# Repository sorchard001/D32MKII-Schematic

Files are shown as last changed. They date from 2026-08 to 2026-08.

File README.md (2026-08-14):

# Dragon 32 MKII Schematic

Captured in KiCad by Stewart Orchard 2015-2026

Original design by Dragon Data Ltd circa 1982

## Why?

The published Dragon schematics do not appear to include MKII versions, which can be a problem for repairs as there are differences in the memory configuration, the video circuit and logic gate pin numbers. I captured this information around the year 1998 with reference to the existing ISS2 schematics, a multimeter and a real MKII ISS6 main board, and have finally got round to recording it as a KiCad project.

## Disclaimer

Much as I would like to think that I've got this 100% correct, there is always the chance that there are mistakes and omissions. I would recommend checking that the information is accurate before using this schematic for anything potentially expensive.

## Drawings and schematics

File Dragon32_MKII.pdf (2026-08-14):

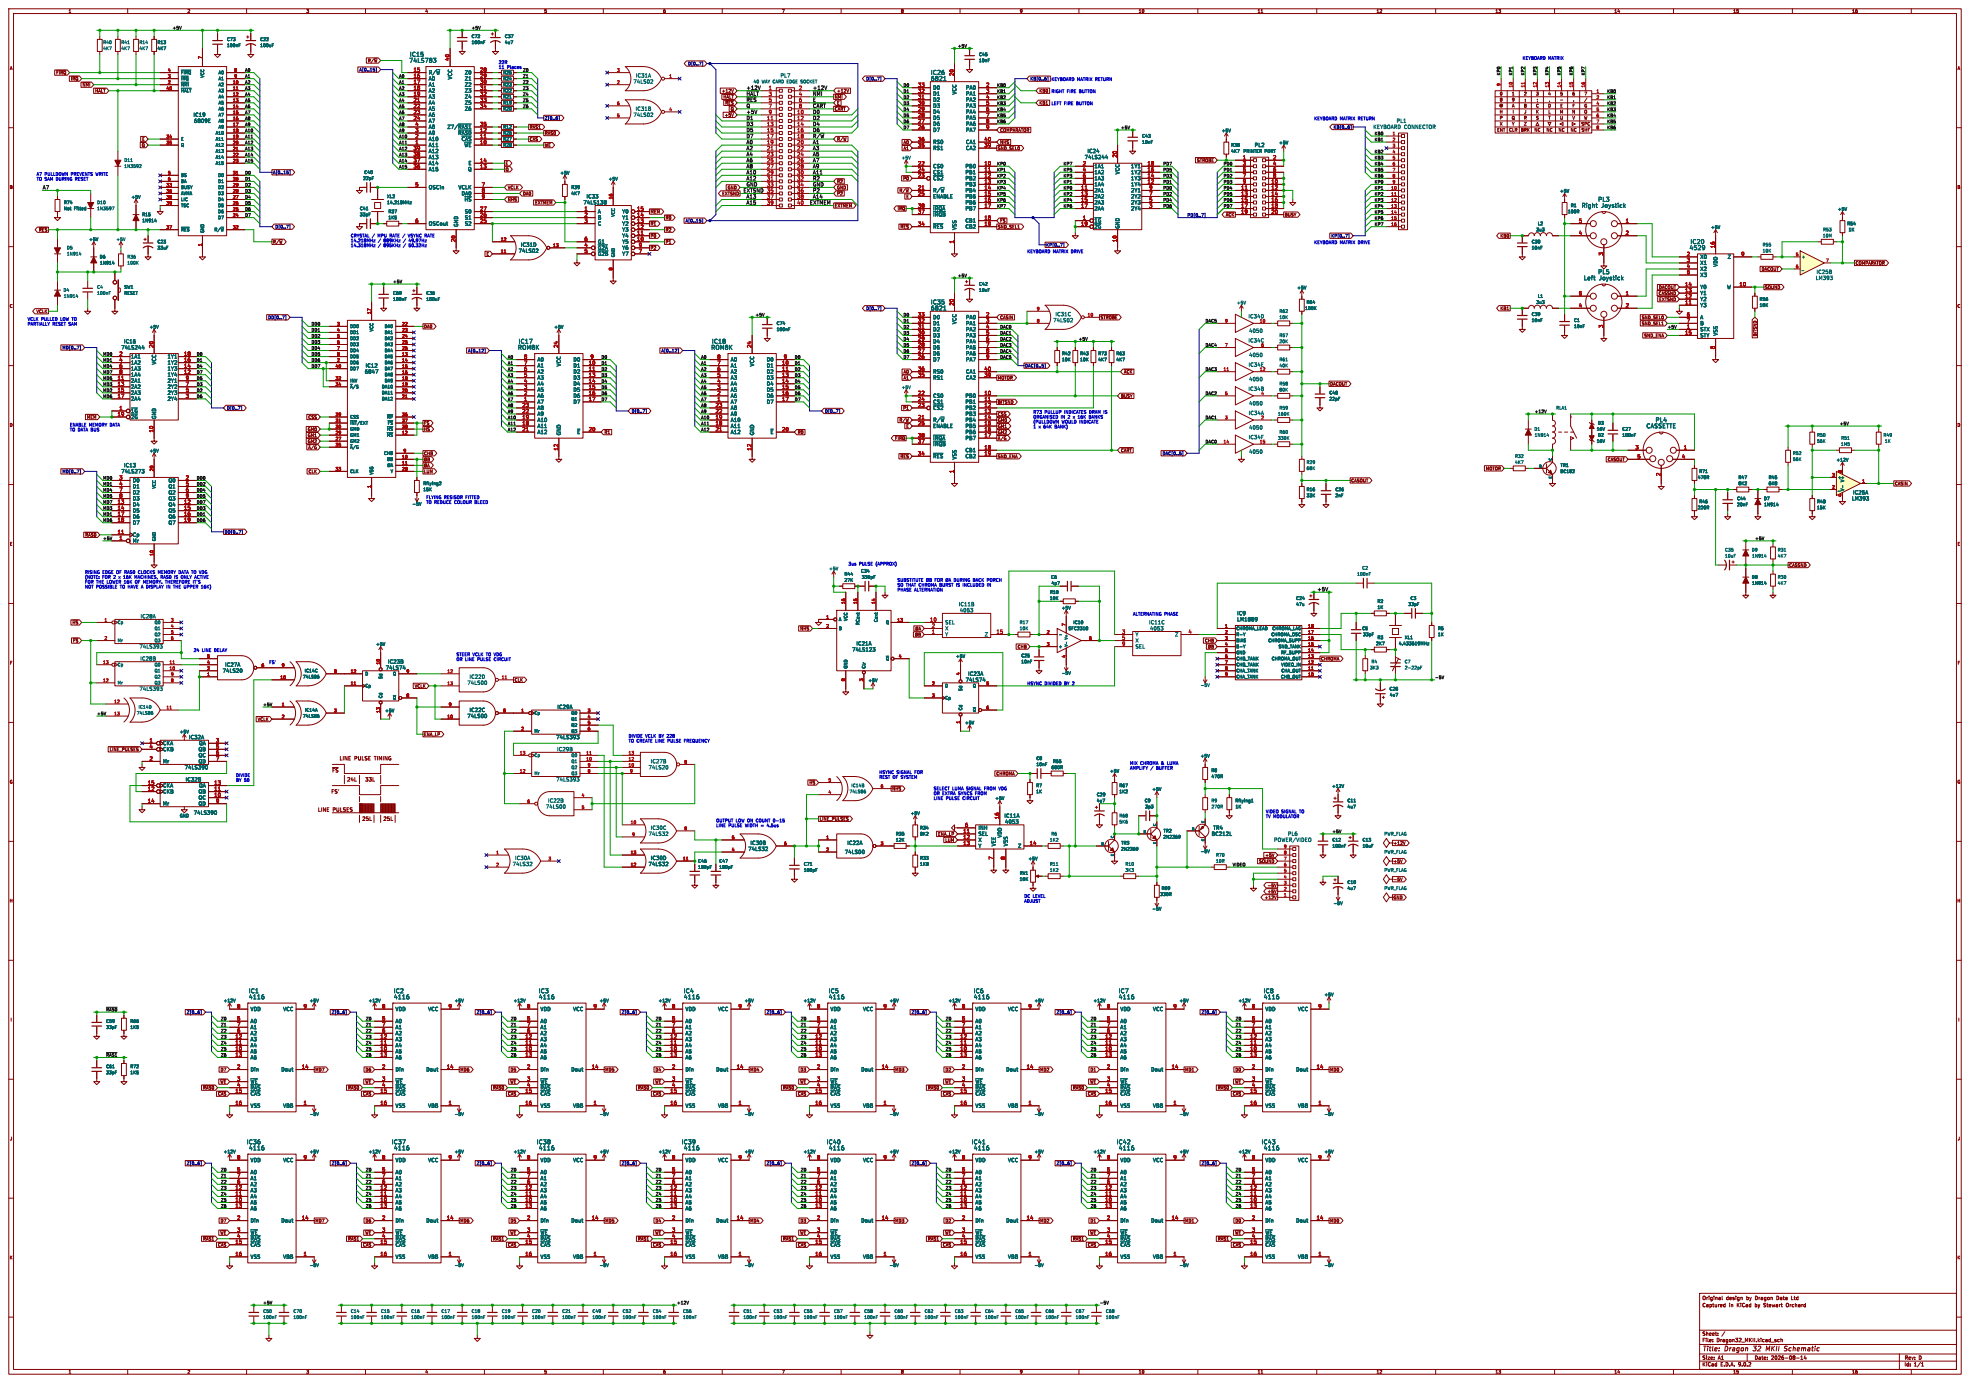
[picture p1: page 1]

VCLK
VCLK PULLED LOW TO
PARTIALLY RESET SAM

1 DA0 22 DA1 23 DA2 24 DA3 25 DA4 26 DA5 13 DA6 14 DA7 15 DA8 16 DA9 18 DA10 19 DA11 20 DA12 21 ~{RP} 36 ~{FS} 37 ~{HS} 38 ~{MS} 12 CHB 9

BUSY
1 x 64K BANK) HSYNC DIVIDED BY 2

R73 PULLUP INDICATES DRAM IS ORGANISED IN 2 x 16K BANKS

ENABLE MEMORY DATA
TO DATA BUS RISING EDGE OF RAS0 CLOCKS MEMORY DATA TO VDG

TO REDUCE COLOUR BLEED

3us PULSE (APPROX) SUBSTITUTE þÿØBFOR þÿØADURING BACK PORCH

(NOTE: FOR 2 x 16K MACHINES, RAS0 IS ONLY ACTIVE
FOR THE LOWER 16K OF MEMORY. THEREFORE IT'S NOT POSSIBLE TO HAVE A DISPLAY IN THE UPPER 16K)

SO THAT CHROMA BURST IS INCLUDED IN
PHASE ALTERNATION

STEER VCLK TO VDG
OR LINE PULSE CIRCUIT

LINE PULSE WIDTH = 4.5us DIVIDE VCLK BY 228 TO CREATE LINE PULSE FREQUENCY

LINE PULSE CIRCUIT HSYNC SIGNAL FOR
REST OF SYSTEM

DC LEVEL ADJUST SELECT LUMA SIGNAL FROM VDG
OR EXTRA SYNCS FROM

OUTPUT LOW ON COUNT 0-15

Id: 1/1 Title: Dragon 32 MKII Schematic

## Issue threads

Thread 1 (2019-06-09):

RAS1 & RAS0 - resistors transposed.

sexyjw, 2019-06-09:
I've noticed a slight error - at least on the Dragon boards I've been looking at. RAS1 from pin 35 of the SAM actually connects to R12, not R26. Likewise, RAS0 from pin 12 connects to R26, not R12.

sorchard001, 2019-06-12:
Many thanks for letting me know. Now fixed!

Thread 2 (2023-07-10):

D11 is reversed on the schematic compared with a populated board

jimbro1000, 2023-07-10:

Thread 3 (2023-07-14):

C52, C54 and C56 wrongly wired

jimbro1000, 2023-07-14:
C52, C54 and C56 connect to +12V, not -5V

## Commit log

2018-07-09 Corrected CASSND/EXTSND inputs to IC20
    [Dragon32_MKII.sch]
2019-06-12 Corrected R12 and R26 (swapped idents)
    These resistors are in series with IC15 SAM RAS1/RAS0 outputs.
    [Dragon32_MKII.sch]
2019-11-04 Updates/corrections
    Added Rflying2 15K resistor to vdg ouput
    Corrected 4116 Vdd to pin 8 (was pin 12)
    Corrected C9 to 3p3 (was 33p)
    Cosmetic tweaks to suit Kicad 5.0.2
    [Dragon32_MKII.sch]
2026-08-14 Updated to KiCad 9
    [Dragon32_MKII.kicad_sch]
2026-08-14 Moved C52, C54 & C56 from -5V to +12V Fixed some ERC issues
    [Dragon32_MKII.kicad_sch, Dragon32_MKII.sch]
2026-08-14 Added keyboard matrix info Updated pdf plot
    [Dragon32_MKII.kicad_sch]
